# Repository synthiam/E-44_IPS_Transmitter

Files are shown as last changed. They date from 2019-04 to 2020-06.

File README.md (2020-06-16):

# E-44 Indoor Positioning System (IPS) Transmitter

**Project Status:** Ready to manufacture

If you are new to GitHub and would like to create a derivative of this project, please have a look at GitHub instructions to [fork a repo](https://help.github.com/en/articles/fork-a-repo)

## Description

Out of our passion to solve the issue of time waste in the robot creation process, ARC was born. The ARC software platform reduces the time it takes to get from idea to implementation. Since 2011 we have been listening to the challenges robot builders encounter and continue to provide them with an ever expanding toolbox of solutions. Join us on this journey!

We didn't stop at the software, we also made time saving hardware solutions. This IPS transmitter reference design is one of them. The IPS transmitter shines a 150° invisible infrared light beam that is picked up by the IPS's infrared camera. A unique feature of this IR transmitter is that it has an extremely wide angle of infrared light dispersion that can be picked up even when the IPS is directly perpendicular to the LED. It also has built-in LED driver circuit that consumes less current, and generates less heat than using classic resistor current limiting. We want to share these files with you so you can create your own version for your community and customers to enjoy!

**Features:**
- Combined with the IPS, this system can be used for night vision
- Switching Power Supply LED driver circuit
- 150° extremely wide angle infrared Light dispersion
- EZ-Builder behavior control available
- Wavelength: 850nm
- Voltage requirement: 4.5-40VDC (7.4V Typical)
- Current draw: 190mA (7.4V), 94mA (16V)
- Dimensions: 15.9(W) x 33.4(L) x 7.1(H) (mm)
- Weight: 3g

**Major components:** 
- AL8861WT-7 LED Driver
- LTE-R38386A-ZF-U IR Emitter 850nm 1A 150° Lens

**Manufacturing notes:** 
1. Manufacturer: Single side placement and soldering of SMT components

This project pairs with the Indoor Positioning System: https://github.com/synthiam/E-39_Indoor_Positioning_System

## Contents

[**Documentation:**](https://github.com/synthiam/E-44_IPS_Transmitter/tree/master/E-44%20Documentation) Schematic PDF, Datasheet PDF, BOM, Assembly PDF

[**Hardware:**](https://github.com/synthiam/E-44_IPS_Transmitter/tree/master/E-44%20Hardware) Altium PCB design File, Altium SCH Design File, Gerbers

*Altium Libraries are also available <a href="https://github.com/synthiam/Synthiam_Altium_Librairies">here</a>*

## Photos

<p align="left">


</p>

## ARC Skill

The ARC skill for this reference design is very easy to use. Simply click on the area you'd like the robot to move to and it moves there! 

Link: https://synthiam.com/Software/Manual/Indoor-Positioning-System-17492



## Contact

For profit use of these files requires written consent. Contact partners@synthiam.com. For everyone else, party on!

Synthiam Website: https://synthiam.com

## License

This project is released under the following license:

**Hardware:** Creative Commons Plus Attribution-NonCommercial 4.0 International (CC+ BY-NC 4.0)

Please see [LICENSE.md](https://github.com/synthiam/E-44_IPS_Transmitter/blob/master/LICENSE.md) for license details.



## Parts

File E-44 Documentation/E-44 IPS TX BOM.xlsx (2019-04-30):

Qty | Description | Manufacturer Part No. | Alternative | Designator | Custom Information | Link
E-44 Indoor Positioning System Transmitter
1 | 2 layer, Blue soldermask, White silkscreen, ENIG | IPS Transmitter Printed Circuit Board |  | PCB
1 | LED Driver IC SOT-25 | AL8861WT-7 |  | U1 |  | https://www.digikey.ca/product-detail/en/diodes-incorporated/AL8861WT-7/AL8861WT-7DICT-ND/6702377
1 | IR Emitter 850nm 1A 150° Lens | LTE-R38386A-ZF-U |  | IR LED |  | https://www.digikey.ca/product-detail/en/lite-on-inc/LTE-R38386A-ZF-U/160-2201-1-ND/6819924
1 | 33uH Fixed Inductor 1.4A 183.3mOhm | NRS6045T330MMGK |  | L1 |  | https://www.digikey.ca/product-detail/en/taiyo-yuden/NRS6045T330MMGK/587-2954-1-ND/2666059
1 | 3 position 2.0mm pitch JST-PH header | S3B-PH-SM4-TB(LF)(SN) |  | P1 |  | https://www.digikey.ca/product-detail/en/jst-sales-america-inc/S3B-PH-SM4-TB-LF-SN/455-1750-1-ND/926847
1 | Schottky Diode 40V 1A SOD-123 | PMEG4010EGWJ |  | D1 |  | https://www.digikey.ca/product-detail/en/nexperia-usa-inc/PMEG4010EGWJ/1727-7336-1-ND/7390587
1 | 0.16ohm 0603 Resistor 1% | ERJ-3BSJR16V |  | R1
1 | 10uF 10V 0603 Ceramic Capacitor | CC0603KRX5R6BB106 |  | C1

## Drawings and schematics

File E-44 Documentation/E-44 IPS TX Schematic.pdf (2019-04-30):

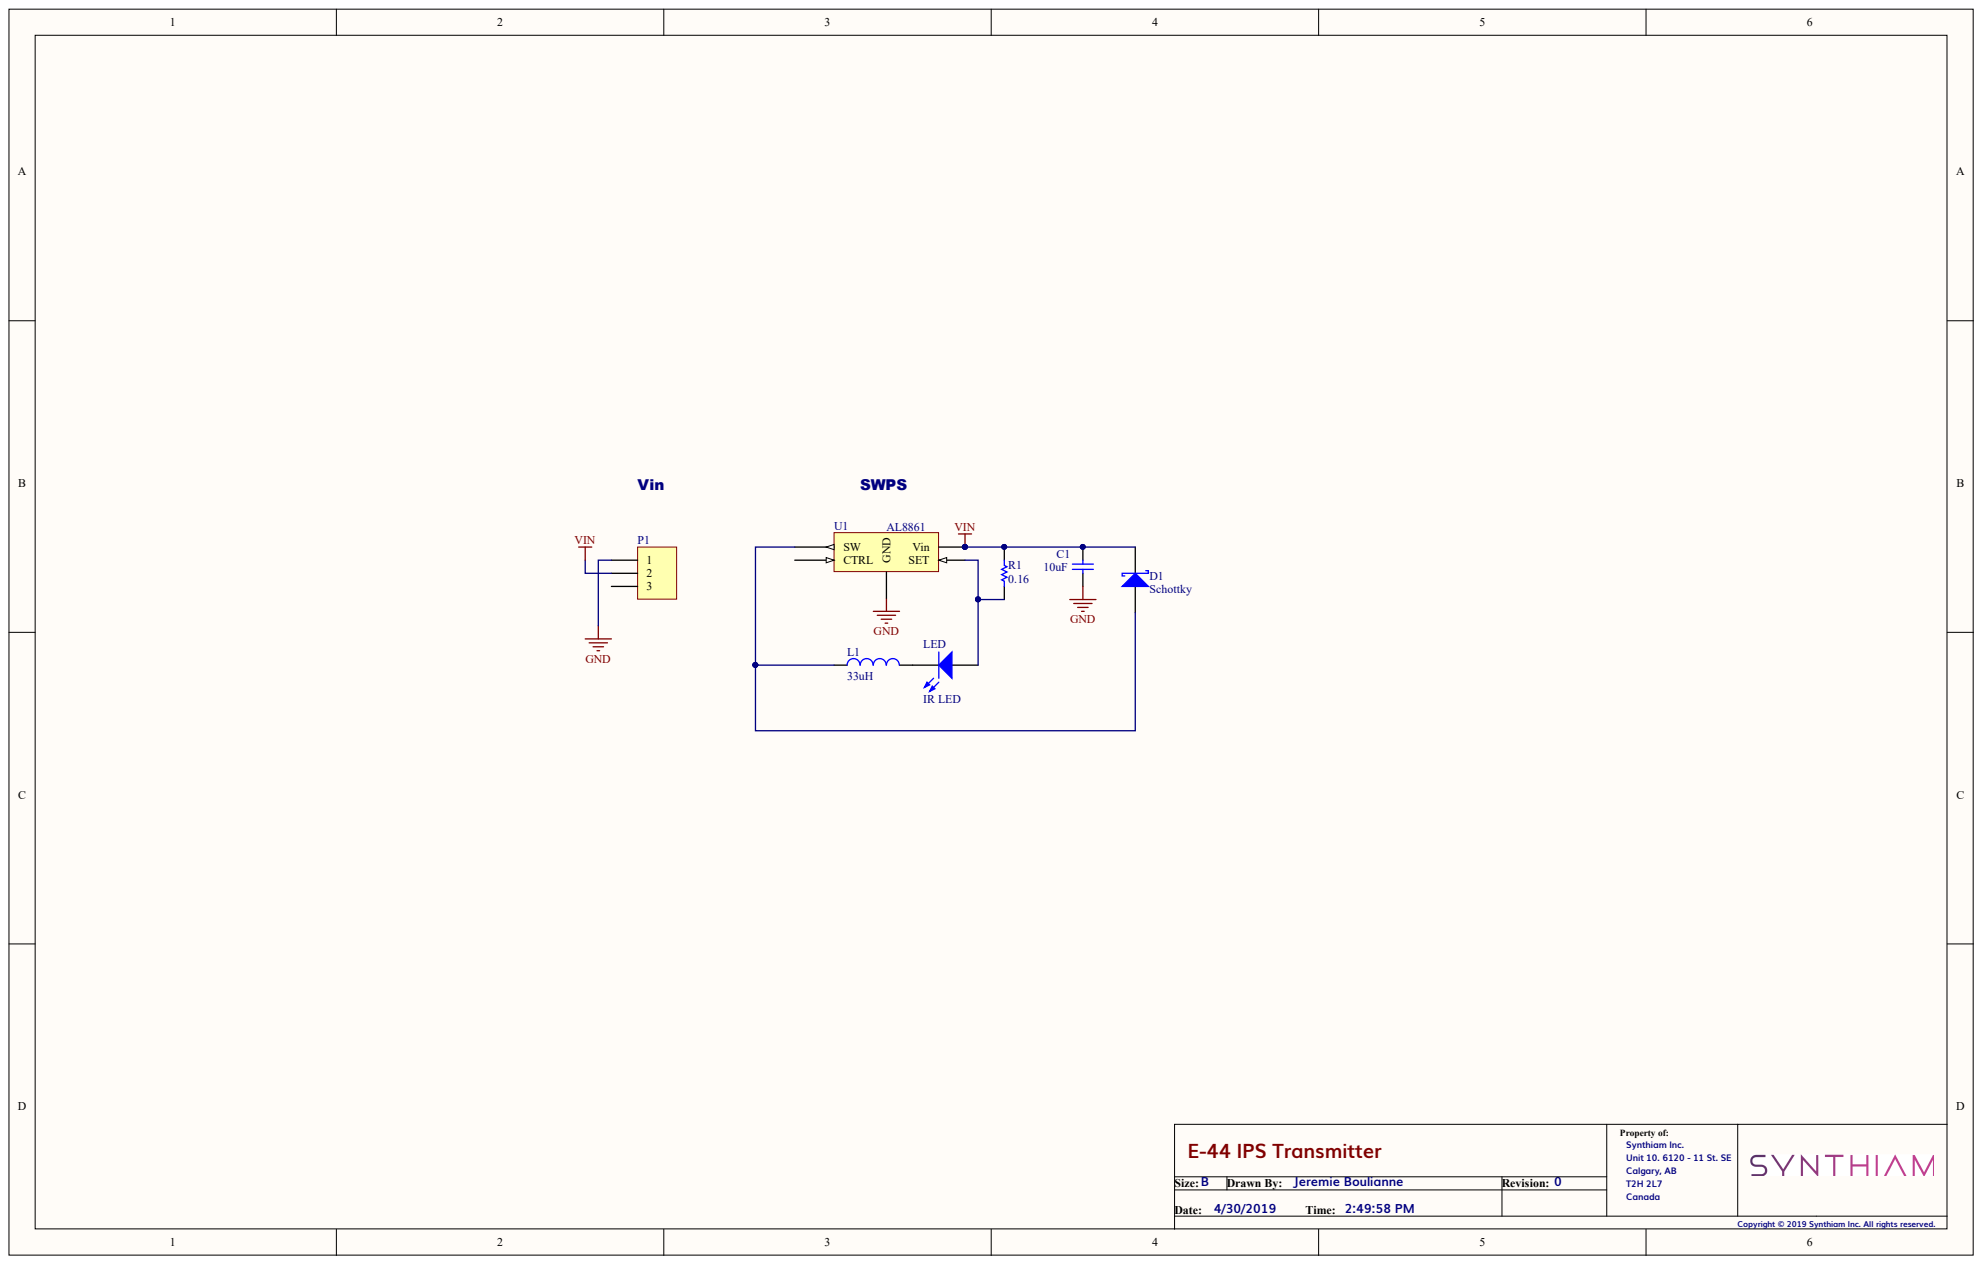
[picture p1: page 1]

E-44 IPS Transmitter | Property of: Synthiam Inc. Unit 10. 6120 - 11 St. SE Calgary, AB T2H 2L7 Canada

B Size: | Jeremie Boulianne Drawn By: | 0 Revision:
4/30/2019 2:49:58 PM Date: Time:

Copyright © 2019 Synthiam Inc. All rights reserved.

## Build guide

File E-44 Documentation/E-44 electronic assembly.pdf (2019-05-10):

# Assembly Instructions

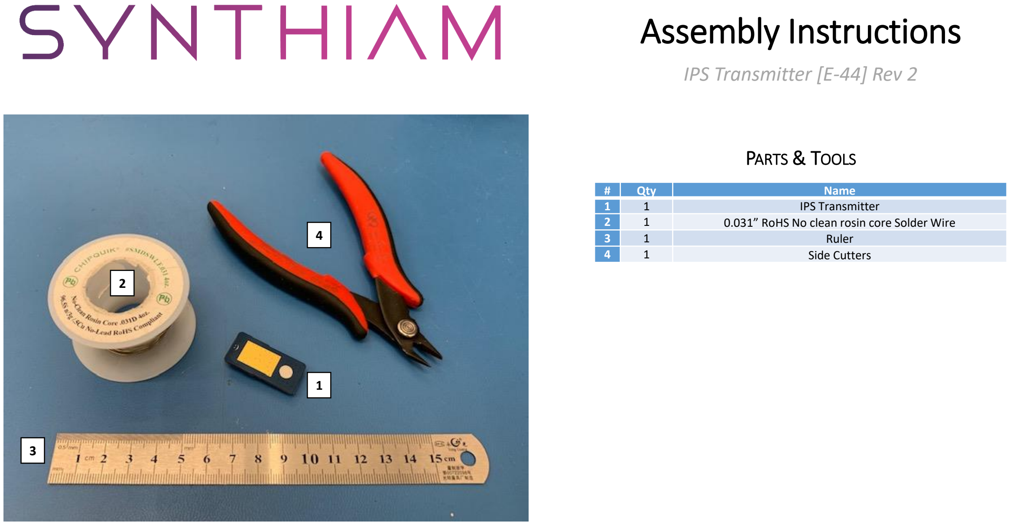
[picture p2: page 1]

# | Qty | Name

1 | 1 | IPS Transmitter
2 | 1 | 0.031” RoHS No clean rosin core Solder Wire
3 | 1 | Ruler
4 | 1 | Side Cutters

IPS Transmitter [E-44] Rev 2

PARTS & TOOLS

1

2

3

4

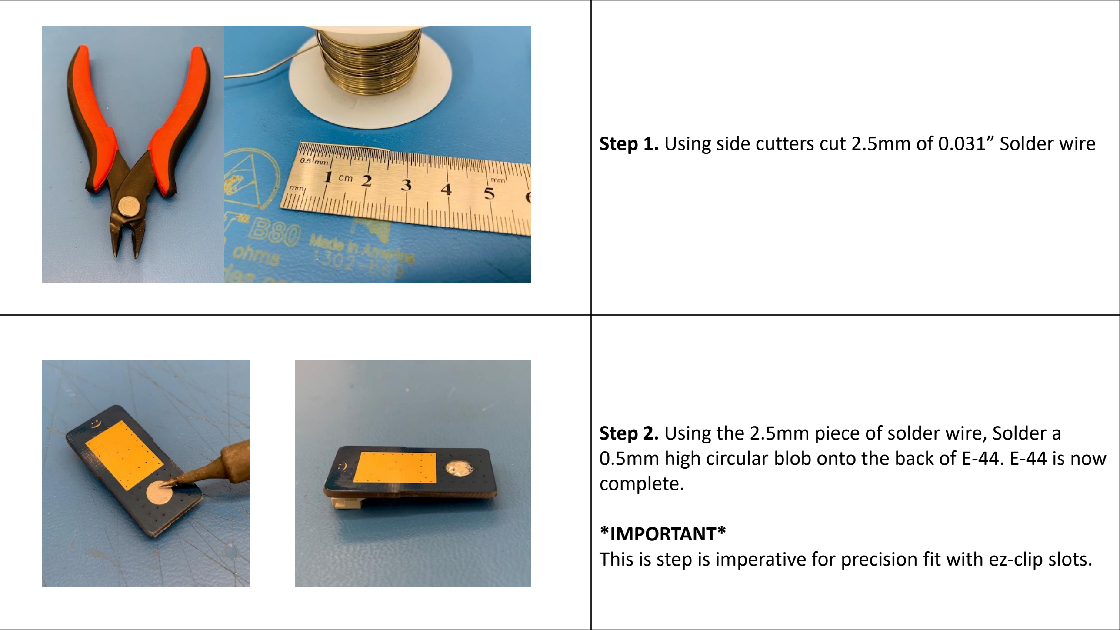
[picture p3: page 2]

Step 1. Using side cutters cut 2.5mm of 0.031” Solder wire
Step 2. Using the 2.5mm piece of solder wire, Solder a 0.5mm high circular blob onto the back of E-44. E-44 is now complete.

*IMPORTANT*
This is step is imperative for precision fit with ez-clip slots.
